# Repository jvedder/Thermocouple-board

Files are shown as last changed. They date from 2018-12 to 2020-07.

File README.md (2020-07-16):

# 4-channel Thermocouple PCB (MAX31855)
## Eagle CAD Schematic and PCB Layout
### Part Number: PCB100 Rev A

This design has 4 channels of **MAX31855** thermocouple amplifiers managed by
an **STM32F042K4** (or **'K6**) ARM Cortex-M0 processor.  Primary communication
and power is RS-485 over Cat 5 UTP Ethernet cables with a POE-like power scheme.
Both full and half-duplex communication schemes are supported. 

Secondary communication is over an **FTDI 232-TTL USB-to-UART** cable.  Direct
communication over **USB** to the STM32 is also supported by the layout (but
has not been tested). Each allow an instance of this board (perhaps without the
MAX31855 populated) to be the RS-485 controller and provide POE power to the
bus from either the USB connection or a 2x5.5 mm power connector.

The RJ-45 Pinout is compatible with the 8-pin modular connector pinout in
**ANSI E1.11-2008 (R2018)** 
 _DMX512-A Asynchronous Serial Digital Data Transmission Standard_  
but has not been tested for interoperability. 

Please note the RS-485 signal naming in this design matches the IC 
manufacturers' convention (A is non-inverting, B is inverting) which is
opposite the RS-485/RS-422 standard (A is inverting, B is non-inverting).

The RJ-45 pins selected for power are also compatible with 10/100 Base-T
Power over Ethernet (POE) in case of a cabling error. External power in the
range of 5V to 12V is supported, but there is little thermal margin on the
LDO at 12V. Lower than 5V is possible if the voltage drop over the cable
is managed.

### Part Number: PCB101 Rev A 

This revision:

- Adds a TPS25921 eFuse to the 2x5.5 mm connector that sources the POE power
injection to ensure that it is current limited.
- Inverts the polarity of the user button so that it can be used for the SMT32
boot loader function.
- Moves the FTDI USART port to PA9/PA10 to support the SMT32 boot loader
function.
- Moves the I2C port to pins PB6/PB7 (USART and I2C were swapped).
- Adds 3 pairs of holes for each channel so that the thermocouple leads can be
tied to the PCB for strain relief.
- Lengthens the PCB.
- Corrects pinout error on button orientation.

## License: ##

[MIT License](../master/LICENSE.txt)

----------------------

A portion of this design was leveraged from the 
**Adafruit Thermocouple Amplifier MAX31855 breakout board**. 
The Adafruit license is copied below. I support Adafruit's open-source hardware.

> Adafruit MAX31885 Thermocouple Amp breakout
> 
> These are the Eagle CAD files for the Adafruit MAX31885 Thermocouple Amp
> breakout:
> 
>   ----> http://www.adafruit.com/products/269
> 
> Adafruit invests time and resources providing this open source design,
> please support Adafruit and open-source hardware by purchasing products
> from Adafruit!
> 
> Thermocouples are very sensitive, requiring a good amplifier with a
> cold-compensation reference. The MAX31855K does everything for you, and can
> be easily interfaced with any microcontroller, even one without an analog
> input. This breakout board has the chip itself, a 3.3V regulator with 10uF
> bypass capacitors and level shifting circuitry, all assembled and tested.
> Comes with a 2 pin terminal block (for connecting to the thermocouple) and pin header (to plug into any breadboard or > perfboard). Goes great with our 1m K-type thermocouple. 
> 
> 
> All text above must be included in any redistribution
> 
> Designed by Limor Fried/Ladyada for Adafruit Industries.
> Creative Commons Attribution/Share-Alike, all text above must be included in
> any redistribution
>

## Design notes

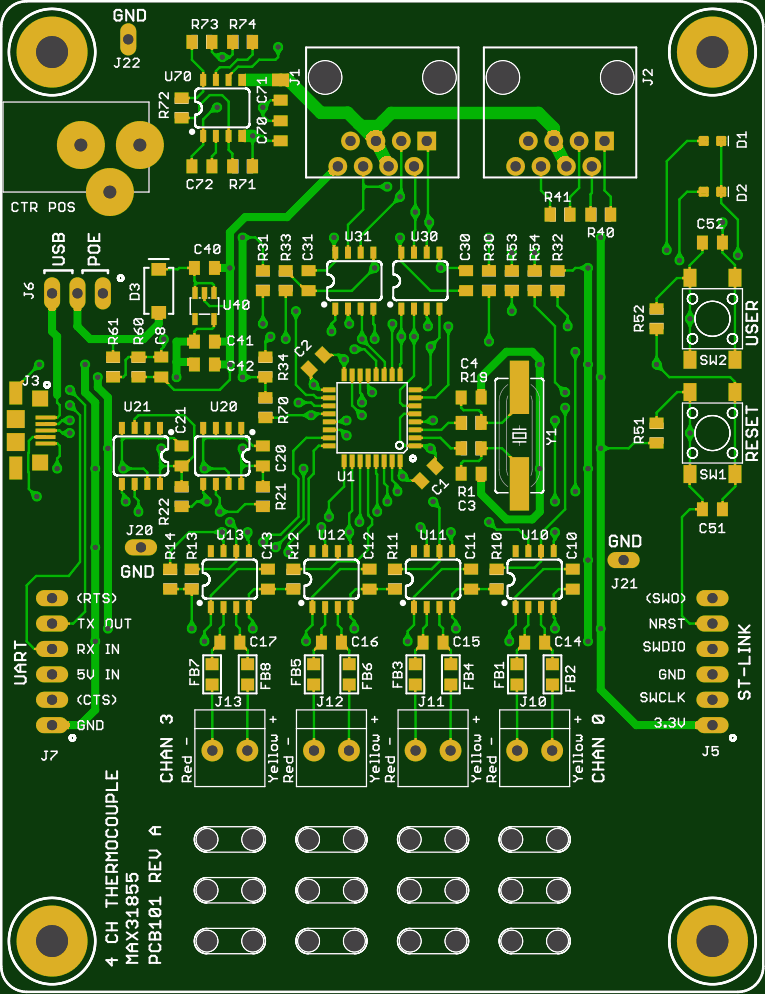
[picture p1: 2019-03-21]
PDF/PCB101_A/Seeed_PCB101_A_top.png

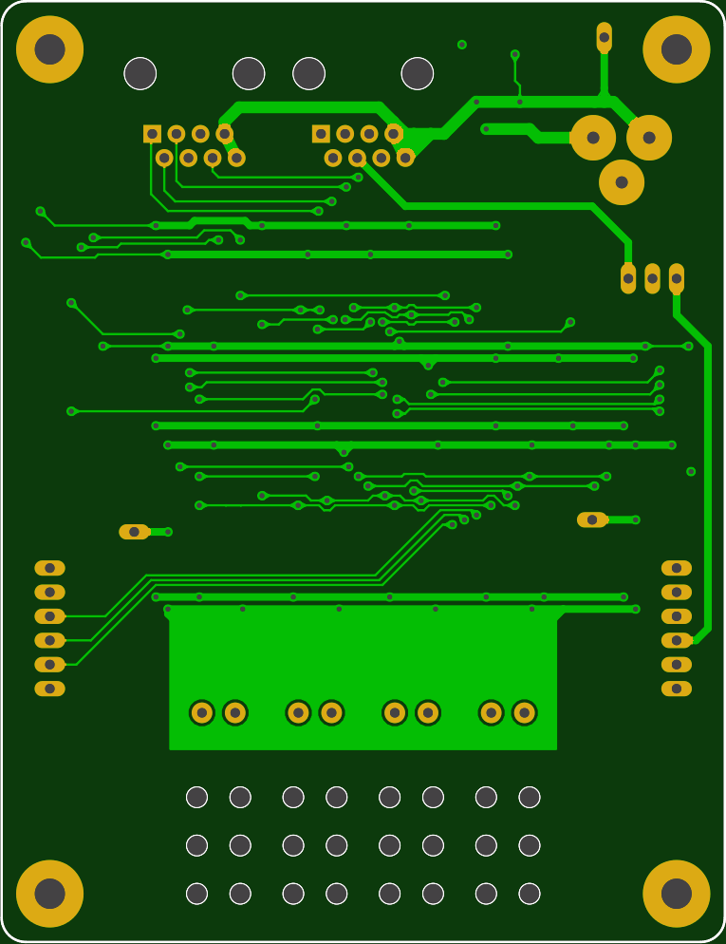
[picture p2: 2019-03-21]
PDF/PCB101_A/Seeed_PCB101_A_bottom.png

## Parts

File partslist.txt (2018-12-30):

Partlist

Exported from Thermocouple-board.brd at 12/27/18 10:27 PM

EAGLE Version 9.2.2 Copyright (c) 1988-2018 Autodesk, Inc.

Assembly variant: 

Part     Value          Package            Library                 Position (inch)       Orientation

C1       0.1uF          C0805K             adafruit                (1.78 1.24)           R225
C2       0.1uF          C0805K             adafruit                (1.34 1.68)           R45
C3       10pF           C0805K             adafruit                (1.95 1.24)           R0
C4       10pF           C0805K             adafruit                (1.95 1.54)           R0
C8       0.1uF          C0805K             adafruit                (0.72 1.66)           R270
C10      0.1uF          C0805K             adafruit                (2.32 0.82)           R90
C11      0.1uF          C0805K             adafruit                (1.93 0.82)           R90
C12      0.1uF          C0805K             adafruit                (1.54 0.82)           R90
C13      0.1uF          C0805K             adafruit                (1.15 0.82)           R90
C14      0.01uF         C0805K             adafruit                (2.17 0.57)           R0
C15      0.01uF         C0805K             adafruit                (1.78 0.57)           R0
C16      0.01uF         C0805K             adafruit                (1.39 0.57)           R0
C17      0.01uF         C0805K             adafruit                (1 0.57)              R0
C20      0.1uF          C0805K             adafruit                (0.59 1.28)           R270
C21      0.1uF          C0805K             adafruit                (0.91 1.28)           R270
C30      0.1uF          C0805K             adafruit                (1.93 2)              R90
C31      0.1uF          C0805K             adafruit                (1.31 2)              R270
C40      1uF            C0805K             adafruit                (0.9 2.05)            R0
C41      10uF           C0805K             adafruit                (0.9 1.76)            R0
C42      10uF           C0805K             adafruit                (0.9 1.67)            R0
C51      0.1uF          C0805K             adafruit                (2.6 1.51)            R180
C52      0.1uF          C0805K             adafruit                (2.59 1.94)           R180
D1       GREEN          LED-0603           SparkFun-LED            (2.24 2)              R90
D2       RED            LED-0603           SparkFun-LED            (2.33 2)              R90
D3       3A/40V/500mV   SMA-DIODE          SparkFun-DiscreteSemi   (0.72 1.96)           R90
FB1      Ferrite        _0805              microbuilder            (2.1 0.42)            R90
FB2      Ferrite        _0805              microbuilder            (2.24 0.42)           R90
FB3      Ferrite        _0805              microbuilder            (1.71 0.42)           R90
FB4      Ferrite        _0805              microbuilder            (1.85 0.42)           R90
FB5      Ferrite        _0805              microbuilder            (1.32 0.42)           R90
FB6      Ferrite        _0805              microbuilder            (1.46 0.42)           R90
FB7      Ferrite        _0805              microbuilder            (0.93 0.42)           R90
FB8      Ferrite        _0805              microbuilder            (1.07 0.42)           R90
J1       RJ45           RJ45-8             SparkFun-Connectors     (0.3 2.44)            R270
J2       RJ45           RJ45-8             SparkFun-Connectors     (2.7 2.44)            R90
J3       1981584-1      1981584-1          audio amplifier example (0 1.41)              R270
J4       2.1MMJACKTHM   PJ-102A            adafruit                (1.12 2.93)           R0
J5       ST-LINK        1X06_OVAL          Thermocouple-board      (2.8 0.75)            R90
J6       HEADER-1X3     1X03_OVAL          Thermocouple-board      (0.22 1.89)           R180
J7       UART           1X06_OVAL          Thermocouple-board      (0.2 0.75)            R270
J10      1X2-3.5MM      1X2-3.5MM          Thermocouple-board      (2.17 0.145)          R180
J11      1X2-3.5MM      1X2-3.5MM          Thermocouple-board      (1.78 0.145)          R180
J12      1X2-3.5MM      1X2-3.5MM          Thermocouple-board      (1.39 0.145)          R180
J13      1X2-3.5MM      1X2-3.5MM          Thermocouple-board      (1 0.145)             R180
MH1      4-40           MTG_HOLE_C280_H125 Thermocouple-board      (0.18 0.18)           R0
MH2      4-40           MTG_HOLE_C280_H125 Thermocouple-board      (2.82 0.18)           R0
MH3      4-40           MTG_HOLE_C280_H125 Thermocouple-board      (0.18 2.92)           R0
MH4      4-40           MTG_HOLE_C280_H125 Thermocouple-board      (2.82 2.92)           R0
R1       10K            R0805              adafruit                (1.95 1.34)           R180
R10      10K            R0805              adafruit                (2.02 0.82)           R90
R11      10K            R0805              adafruit                (1.63 0.82)           R90
R12      10K            R0805              adafruit                (1.24 0.82)           R90
R13      10K            R0805              adafruit                (0.85 0.82)           R90
R14      10K            R0805              adafruit                (0.76 0.82)           R90
R19      10K            R0805              adafruit                (1.95 1.44)           R180
R21      10K            R0805              adafruit                (0.59 1.45)           R90
R22      10K            R0805              adafruit                (0.91 1.45)           R90
R30      10K            R0805              adafruit                (2.02 2)              R270
R31      10K            R0805              adafruit                (1.13 2)              R270
R32      10K            R0805              adafruit                (2.11 2)              R90
R33      10K            R0805              adafruit                (1.22 2)              R90
R34      10K            R0805              adafruit                (1.14 1.66)           R90
R51      10K            R0805              adafruit                (2.6 1.39)            R0
R52      10K            R0805              adafruit                (2.59 1.82)           R0
R53      470            R0805              adafruit                (2.24 1.83)           R90
R54      470            R0805              adafruit                (2.33 1.83)           R90
R60      10K            R0805              adafruit                (0.63 1.66)           R270
R61      10K            R0805              adafruit                (0.54 1.66)           R270
R70      10K            R0805              adafruit                (0.63 0.93)           R90
SW1      PUSHBUTTON     PUSHBUTTON_6X6MM   Thermocouple-board      (2.81 1.45)           R270
SW2      PUSHBUTTON     PUSHBUTTON_6X6MM   Thermocouple-board      (2.81 1.88)           R270
U1       STM32F042K4    TQFP32-0.8MM       Thermocouple-board      (1.56 1.46)           R180
U10      MAX31855       SO08               adafruit                (2.17 0.82)           R0
U11      MAX31855       SO08               adafruit                (1.78 0.82)           R0
U12      MAX31855       SO08               adafruit                (1.39 0.82)           R0
U13      MAX31855       SO08               adafruit                (1 0.82)              R0
U20      EEPROM-I2C     SO08               Thermocouple-board      (0.75 1.28)           R0
U21      EEPROM-I2C     SO08               Thermocouple-board      (1.07 1.28)           R0
U30      ST3485         SO08               SparkFun-IC-Comms       (1.75 2)              R0
U31      ST3485         SO08               SparkFun-IC-Comms       (1.49 2)              R0
U40      LP298XS        SOT23-5L           adafruit                (0.9 1.9)             R180
Y1       8MHz           HC49UP             SparkFun-Clocks         (2.14 1.39)           R90

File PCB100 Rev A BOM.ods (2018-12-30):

Bill of Materials
4 Channel Thermocouple Board (MAX31855)
PCB100 Rev A
28-Dec-2018
Manufacturer Part Number | Manufacturer | Digi-Key Part Number | Customer Reference | Reference Designator | Packaging | Quantity | Unit Price | Extended Price | Description
KTR10EZPF4700 | Rohm Semiconductor | RHM470AHCT-ND |  | R53, R54 | Cut Tape (CT) | 2 | $0.1800 | $0.36 | RES SMD 470 OHM 1% 1/8W 0805
885342207005 | Wurth Electronics Inc. | 732-12105-1-ND |  | C14,C15,C16,C17 | Cut Tape (CT) | 4 | $0.1000 | $0.40 | CAP CER 10000PF 200V X7R 0805
885012207098 | Wurth Electronics Inc. | 732-8080-1-ND |  | C1,C2,C8,C10,C11,C12,C13,C20,C21,C30,C31,C51,C52 | Cut Tape (CT) | 13 | $0.0740 | $0.96 | CAP CER 0.1UF 50V X7R 0805
RMCF0805FT10K0 | Stackpole Electronics Inc. | RMCF0805FT10K0CT-ND |  | R1,R10,R11,R12,R13,R14,R19,R21,R22,R30,R31,R32,R33,R34,R51,R52,R60,R70 | Cut Tape (CT) | 18 | $0.0270 | $0.49 | RES 10K OHM 1% 1/8W 0805
885012007051 | Wurth Electronics Inc. | 732-7846-1-ND |  | C3,C4 | Cut Tape (CT) | 2 | $0.1000 | $0.20 | CAP CER 10PF 50V C0G/NP0 0805
CL21A106KOQNNNE | Samsung Electro-Mechanics | 1276-1096-1-ND |  | C41,C42 | Cut Tape (CT) | 2 | $0.2100 | $0.42 | CAP CER 10UF 16V X5R 0805
10104111-0001LF | Amphenol ICC (FCI) | 609-4053-1-ND |  | J3 | Cut Tape (CT) | 1 | $0.8100 | $0.81 | CONN RCPT USB2.0 MICRO AB SMD RA
CL21B105KAFNNNE | Samsung Electro-Mechanics | 1276-1066-1-ND |  | C40 | Cut Tape (CT) | 1 | $0.1100 | $0.11 | CAP CER 1UF 25V X7R 0805
YO0201500000G | Amphenol Anytek | 609-4725-ND |  | J10,J11,J12,J13 | Bulk | 4 | $0.7300 | $2.92 | TERM BLK 2POS SIDE ENT 3.5MM PCB
PJ-102A | CUI Inc. | CP-102A-ND |  | J4 | Tray | 1 | $0.6700 | $0.67 | CONN PWR JACK 2X5.5MM SOLDER
B340AE-13 | Diodes Incorporated | B340AE-13DICT-ND |  | D3 | Cut Tape (CT) | 1 | $0.4000 | $0.40 | DIODE SCHOTTKY 40V 2A SMA
ABLS-8.000MHZ-B4-T | Abracon LLC | 535-10212-1-ND |  | Y1 | Cut Tape (CT) | 1 | $0.2700 | $0.27 | CRYSTAL 8.0000MHZ 18PF SMD
BKP2125HS600-T | Taiyo Yuden | 587-1932-1-ND | Alternate 1 | FB1,FB2,FB3,FB4,FB5,FB6,FB7,FB8 | Cut Tape (CT) | 8 | $0.1000 | $0.80 | FERRITE BEAD 60 OHM 0805 1LN
BK2125HM601-T | Taiyo Yuden | 587-1902-1-ND | Alternate 2 | FB1,FB2,FB3,FB4,FB5,FB6,FB7,FB8 | Cut Tape (CT) | 8 | $0.1000 | $0.80 | FERRITE BEAD 600 OHM 0805 1LN
LTST-C190KGKT | Lite-On Inc. | 160-1435-1-ND |  | D1 | Cut Tape (CT) | 1 | $0.2700 | $0.27 | LED GREEN CLEAR CHIP SMD
LTST-C190KRKT | Lite-On Inc. | 160-1436-1-ND |  | D2 | Cut Tape (CT) | 1 | $0.2700 | $0.27 | LED RED CLEAR CHIP SMD
LP2985-33DBVR | Texas Instruments | 296-18476-1-ND |  | U40 | Cut Tape (CT) | 1 | $0.6000 | $0.60 | IC REG LINEAR 3.3V 150MA SOT23-5
MAX31855KASA+ | Maxim Integrated | MAX31855KASA+-ND |  | U10,U11,U12,U13 | Tube | 4 | $4.5000 | $18.00 | IC CONV THERMOCOUPLE-DGTL SOIC
PTS645SL50SMTR92 LFS | C&K | CKN9088CT-ND | BLACK | SW1 | Cut Tape (CT) | 1 | $0.1700 | $0.17 | SWITCH TACTILE SPST-NO 0.05A 12V
PTS645SM50SMTR92 LFS | C&K | CKN10889CT-ND | BLUE | SW2 | Cut Tape (CT) | 1 | $0.2700 | $0.27 | SWITCH TACTILE SPST-NO 0.05A 12V
54602-908LF | Amphenol ICC (FCI) | 609-1046-ND |  | J1,J2 | Bulk | 2 | $0.6000 | $1.20 | CONN MOD JACK 8P8C R/A UNSHLD
ST3485ECDR | STMicroelectronics | 497-6540-1-ND |  | U30,U31 | Cut Tape (CT) | 2 | $1.5900 | $3.18 | IC TXRX RS422/485 15MBPS 8SO
STM32F042K6T6 | STMicroelectronics | 497-14647-ND |  | U1 | Tray | 1 | $3.0100 | $3.01 | IC MCU 32BIT 32KB FLASH 32LQFP
CR0805-FX-3012ELF | Bourns Inc. | CR0805-FX-3012ELFCT-ND |  | C61 | Cut Tape (CT) | 1 | $0.1000 | $0.10 | RES SMD 30.1K OHM 1% 1/8W 0805
CRG0805F750R | TE Connectivity Passive Product | A126385CT-ND |  | TERM-BIAS2 | Cut Tape (CT) | 2 | $0.1000 | $0.20 | RES SMD 750 OHM 1% 1/8W 0805
RC0805FR-07137RL | Yageo | 311-137CRCT-ND |  | TERM-BIAS1 | Cut Tape (CT) | 1 | $0.1000 | $0.10 | RES SMD 137 OHM 1% 1/8W 0805
RC0805FR-07100RL | Yageo | 311-100CRCT-ND |  | TERM | Cut Tape (CT) | 1 | $0.1000 | $0.10 | RES SMD 100 OHM 1% 1/8W 0805
Header, 1x3 |  |  | On-Hand | J6 |  | 1 |  |  | Header, 1x3, 0.1-inch
Header, 1x6 |  |  | On-Hand | J5, J7 |  | 2 |  |  | Header, 1x6, 0.1-inch
 |  |  |  |  | Totals | 85 |  | $37.08

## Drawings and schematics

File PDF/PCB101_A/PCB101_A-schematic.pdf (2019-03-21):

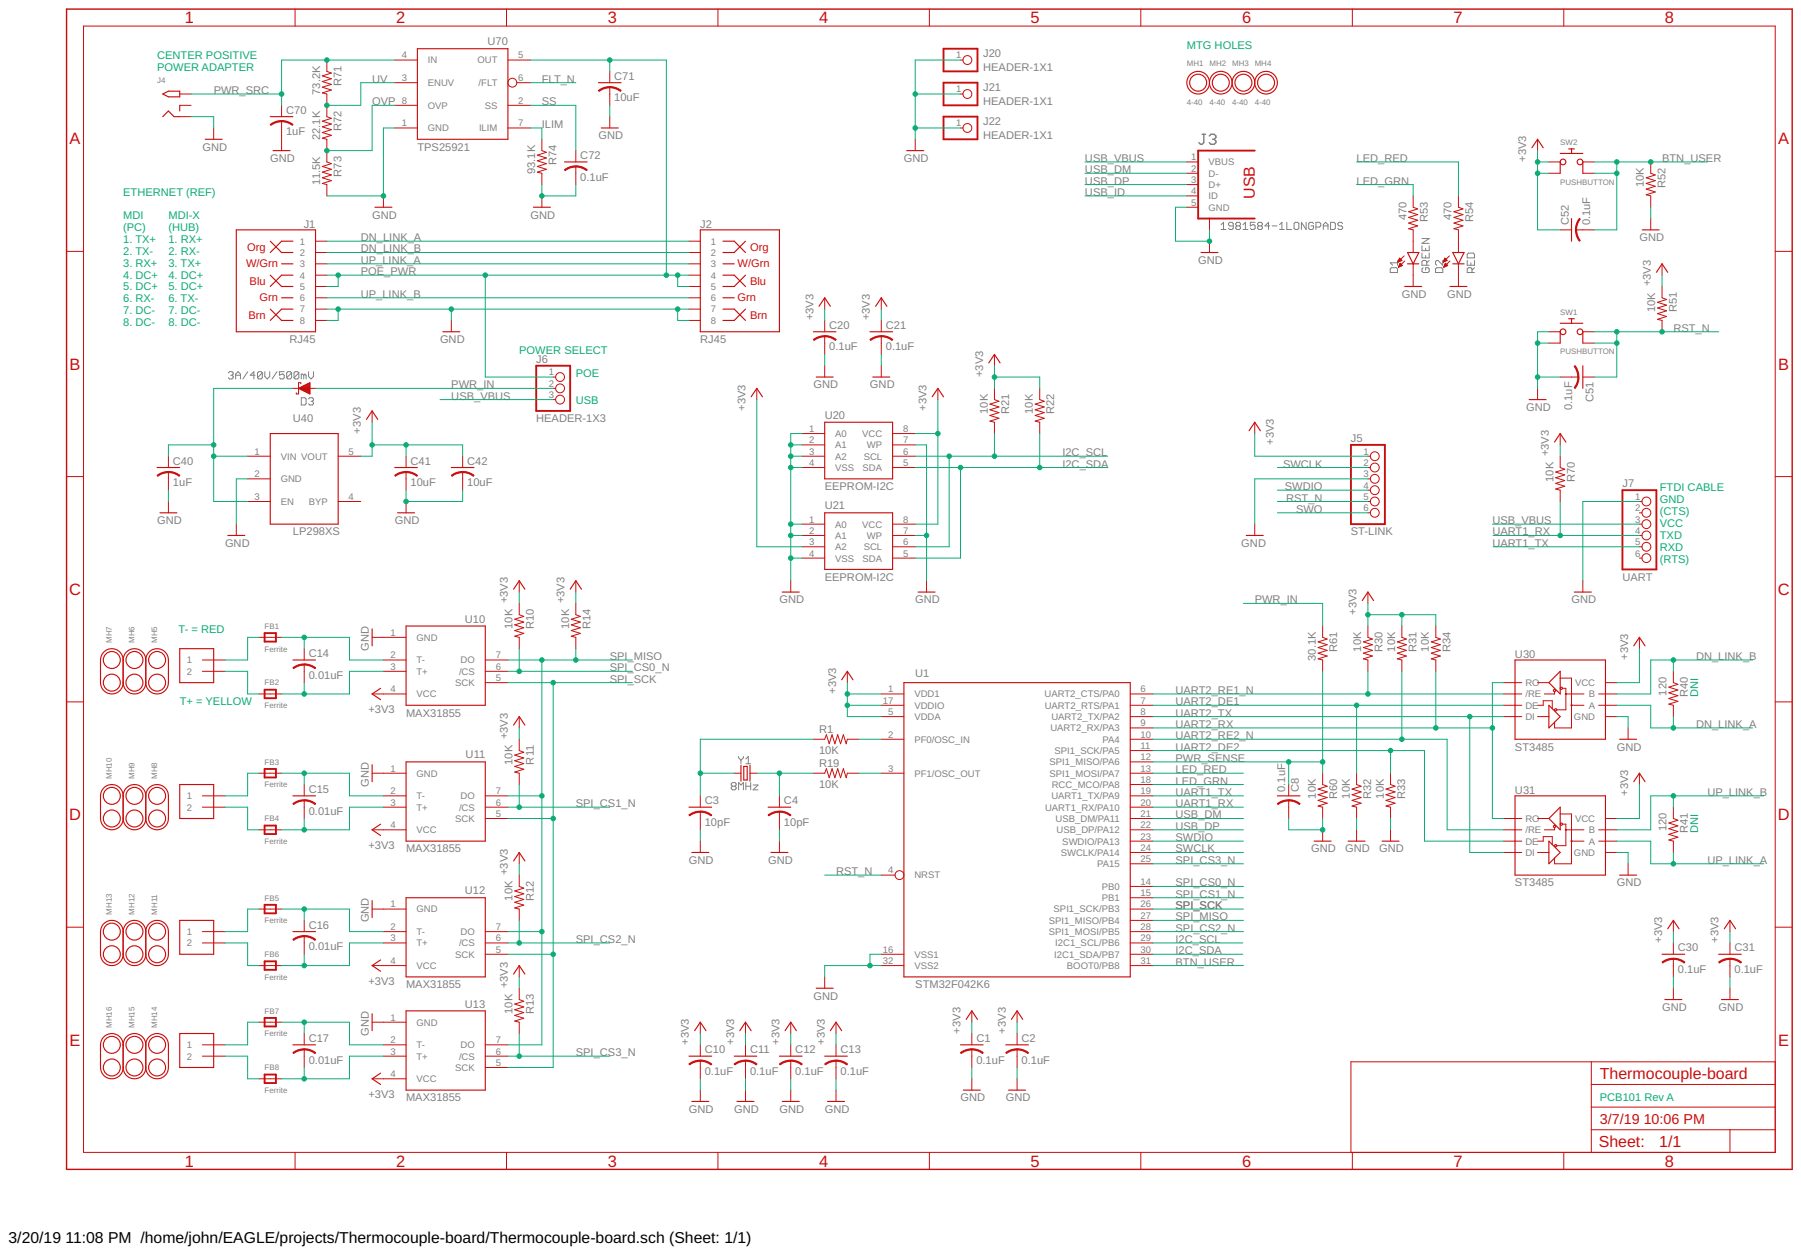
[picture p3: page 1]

MTG HOLES

POE_PWR | Blu Brn W/Grn Grn Org

UP_LINK_B

3/20/19 11:08 PM /home/john/EAGLE/projects/Thermocouple-board/Thermocouple-board.sch (Sheet: 1/1)

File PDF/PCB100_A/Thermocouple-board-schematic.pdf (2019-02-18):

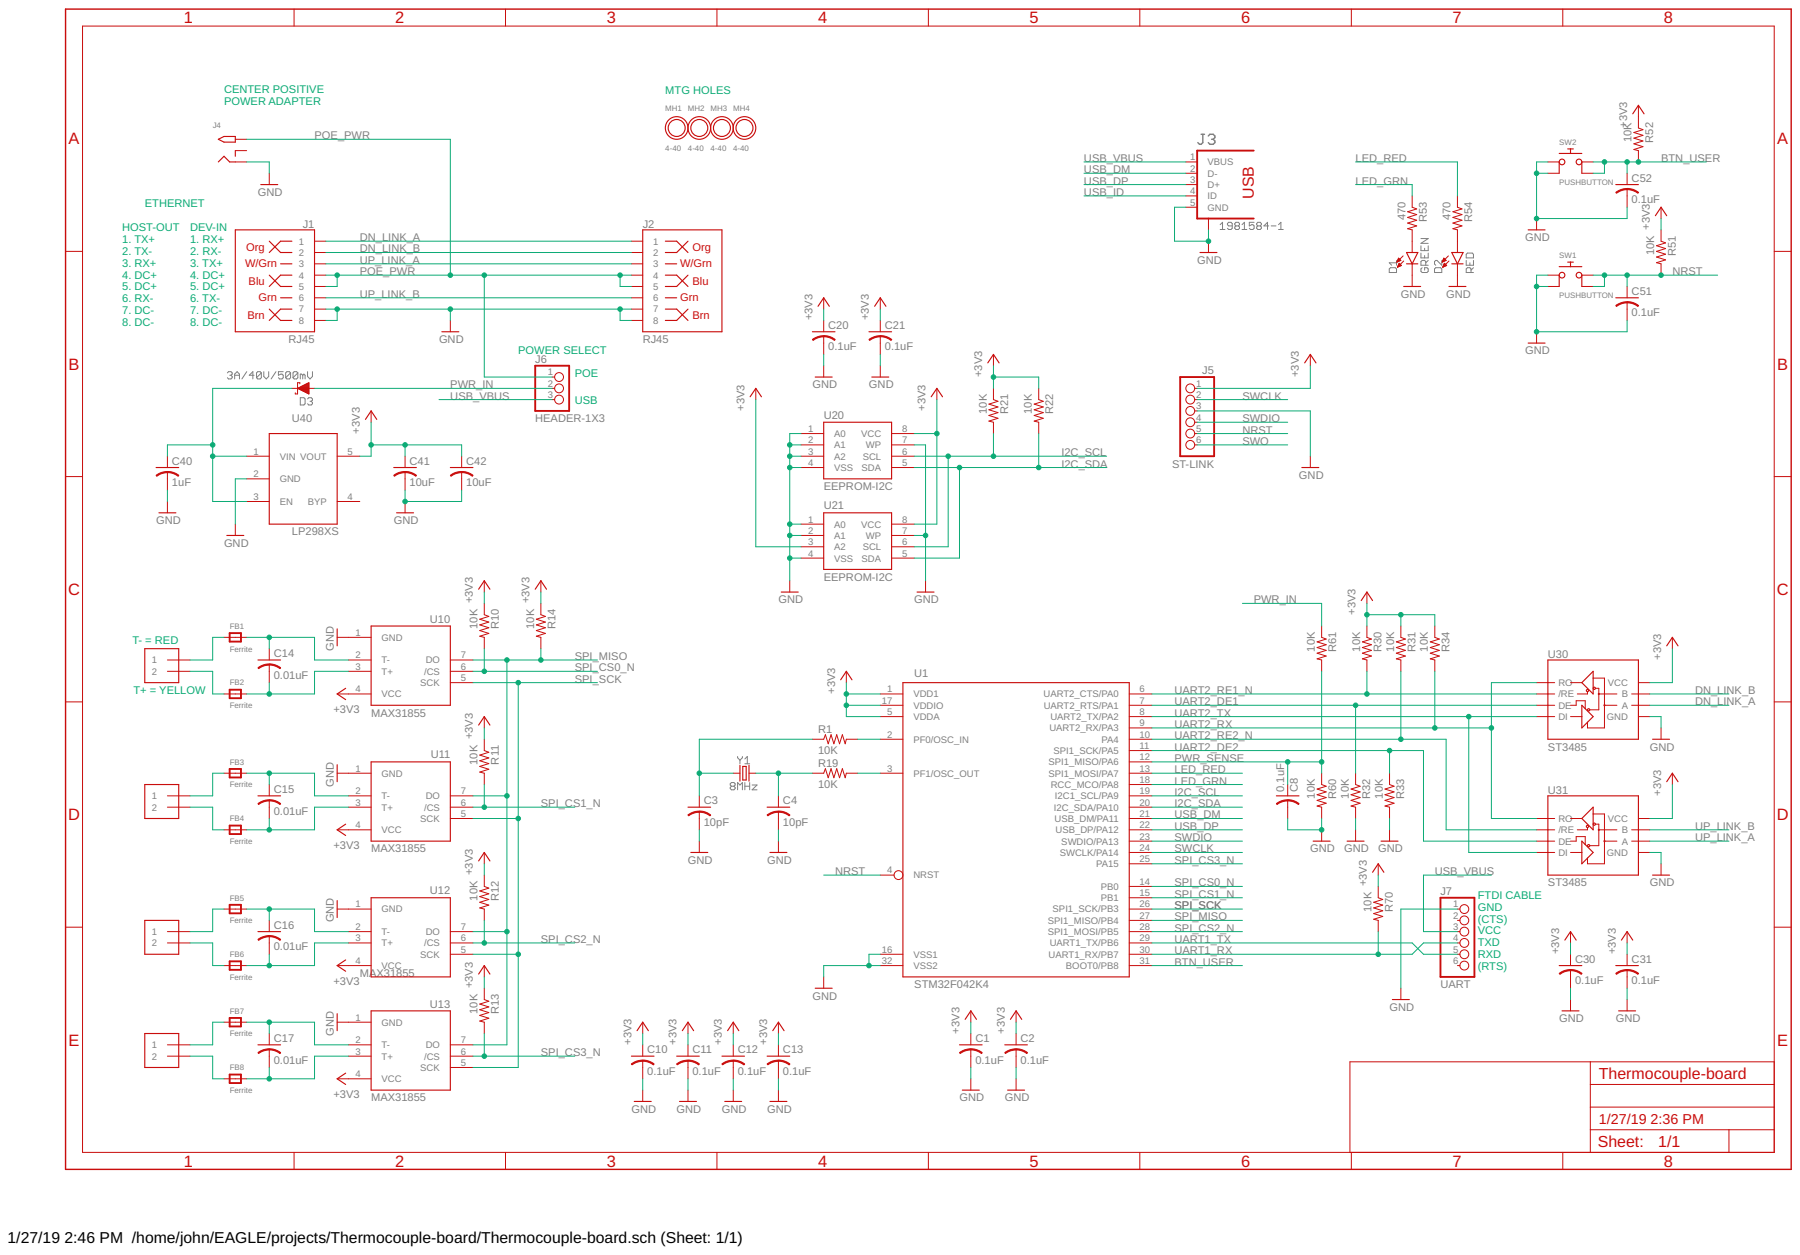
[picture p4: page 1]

POE_PWR | Blu Brn W/Grn Grn Org

UP_LINK_B

1/27/19 2:46 PM /home/john/EAGLE/projects/Thermocouple-board/Thermocouple-board.sch (Sheet: 1/1)

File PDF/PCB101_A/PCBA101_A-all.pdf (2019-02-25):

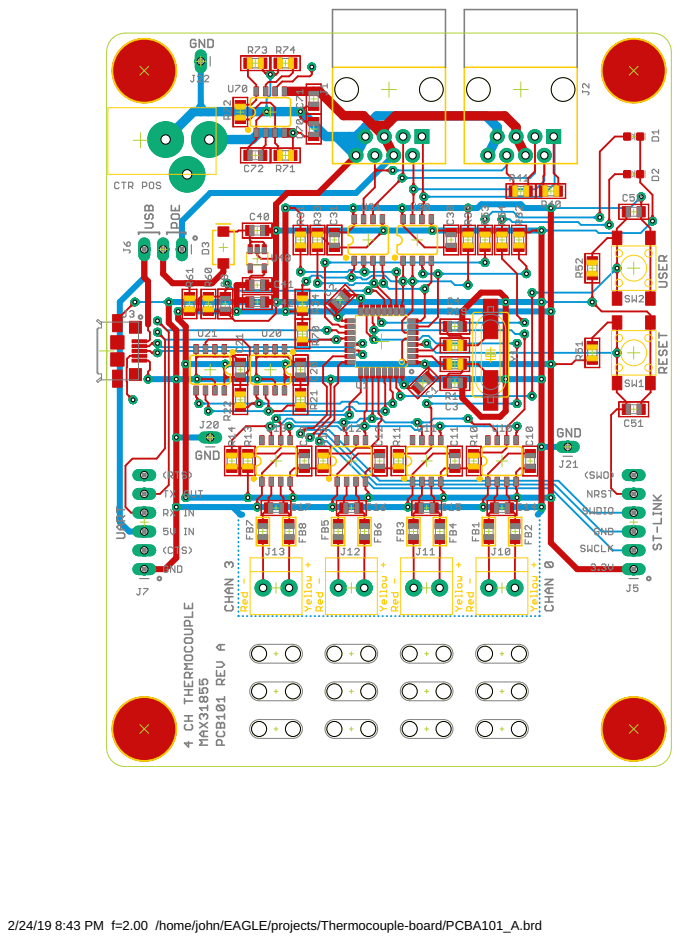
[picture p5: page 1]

2/24/19 8:43 PM f=2.00 /home/john/EAGLE/projects/Thermocouple-board/PCBA101_A.brd

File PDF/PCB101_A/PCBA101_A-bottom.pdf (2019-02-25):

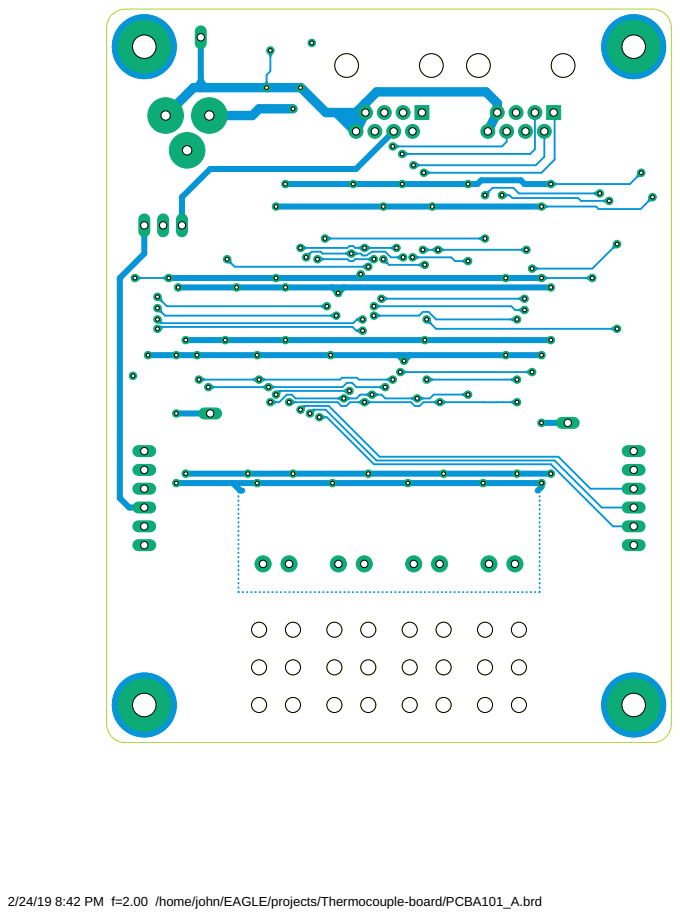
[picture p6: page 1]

2/24/19 8:42 PM f=2.00 /home/john/EAGLE/projects/Thermocouple-board/PCBA101_A.brd

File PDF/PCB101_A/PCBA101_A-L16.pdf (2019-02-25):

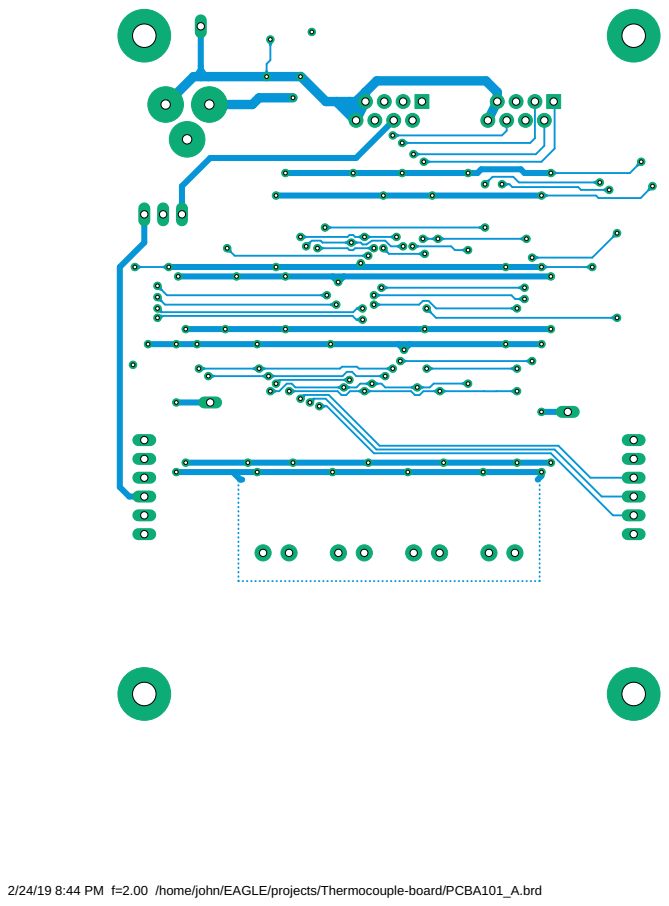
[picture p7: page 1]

2/24/19 8:44 PM f=2.00 /home/john/EAGLE/projects/Thermocouple-board/PCBA101_A.brd

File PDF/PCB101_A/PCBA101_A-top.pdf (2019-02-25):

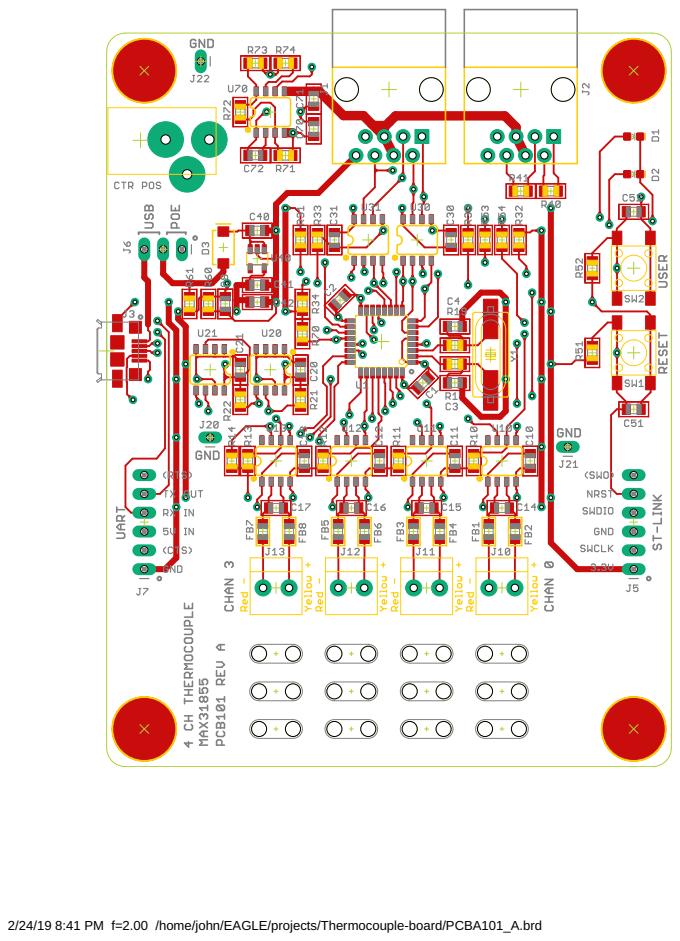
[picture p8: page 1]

2/24/19 8:41 PM f=2.00 /home/john/EAGLE/projects/Thermocouple-board/PCBA101_A.brd

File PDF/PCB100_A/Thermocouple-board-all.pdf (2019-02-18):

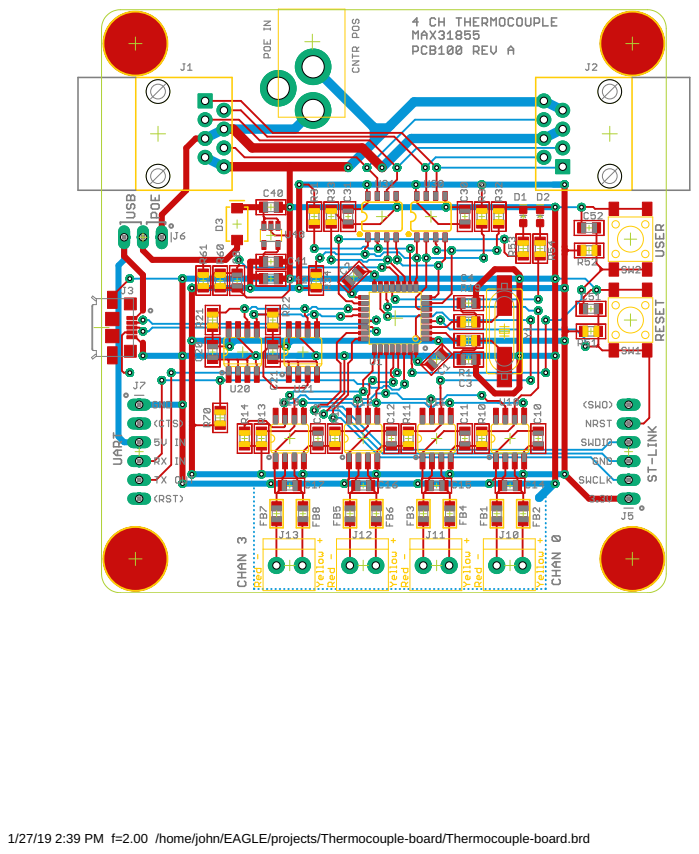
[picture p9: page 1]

1/27/19 2:39 PM f=2.00 /home/john/EAGLE/projects/Thermocouple-board/Thermocouple-board.brd

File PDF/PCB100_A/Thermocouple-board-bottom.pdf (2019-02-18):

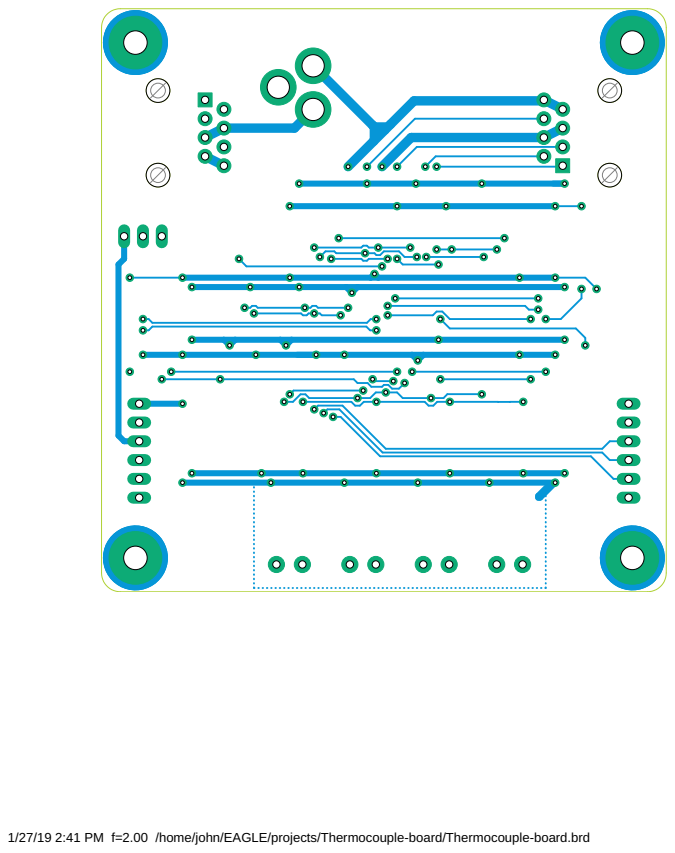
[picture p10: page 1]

1/27/19 2:41 PM f=2.00 /home/john/EAGLE/projects/Thermocouple-board/Thermocouple-board.brd

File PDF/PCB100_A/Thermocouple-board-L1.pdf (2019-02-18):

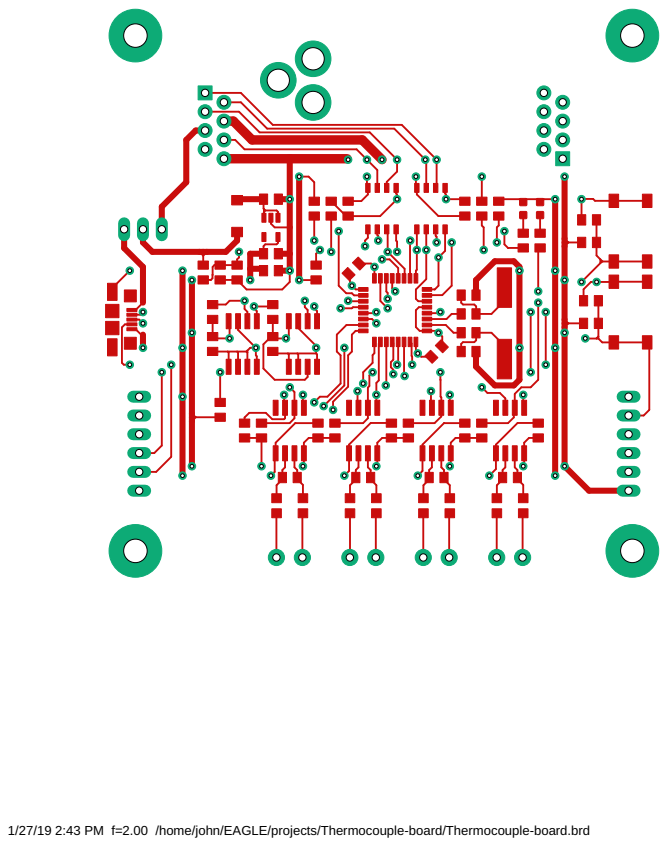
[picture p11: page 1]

1/27/19 2:43 PM f=2.00 /home/john/EAGLE/projects/Thermocouple-board/Thermocouple-board.brd

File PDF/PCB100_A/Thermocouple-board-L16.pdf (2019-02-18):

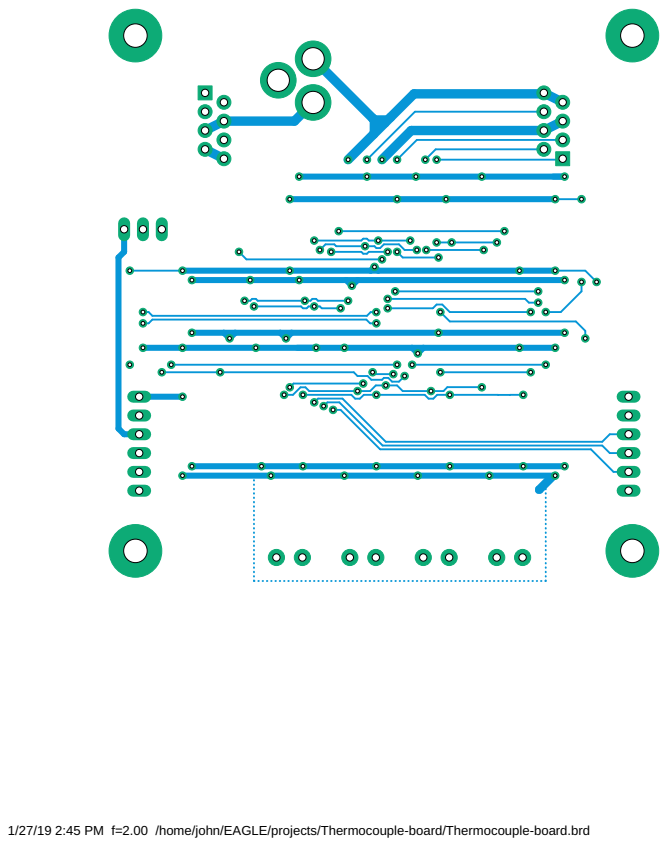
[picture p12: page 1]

1/27/19 2:45 PM f=2.00 /home/john/EAGLE/projects/Thermocouple-board/Thermocouple-board.brd

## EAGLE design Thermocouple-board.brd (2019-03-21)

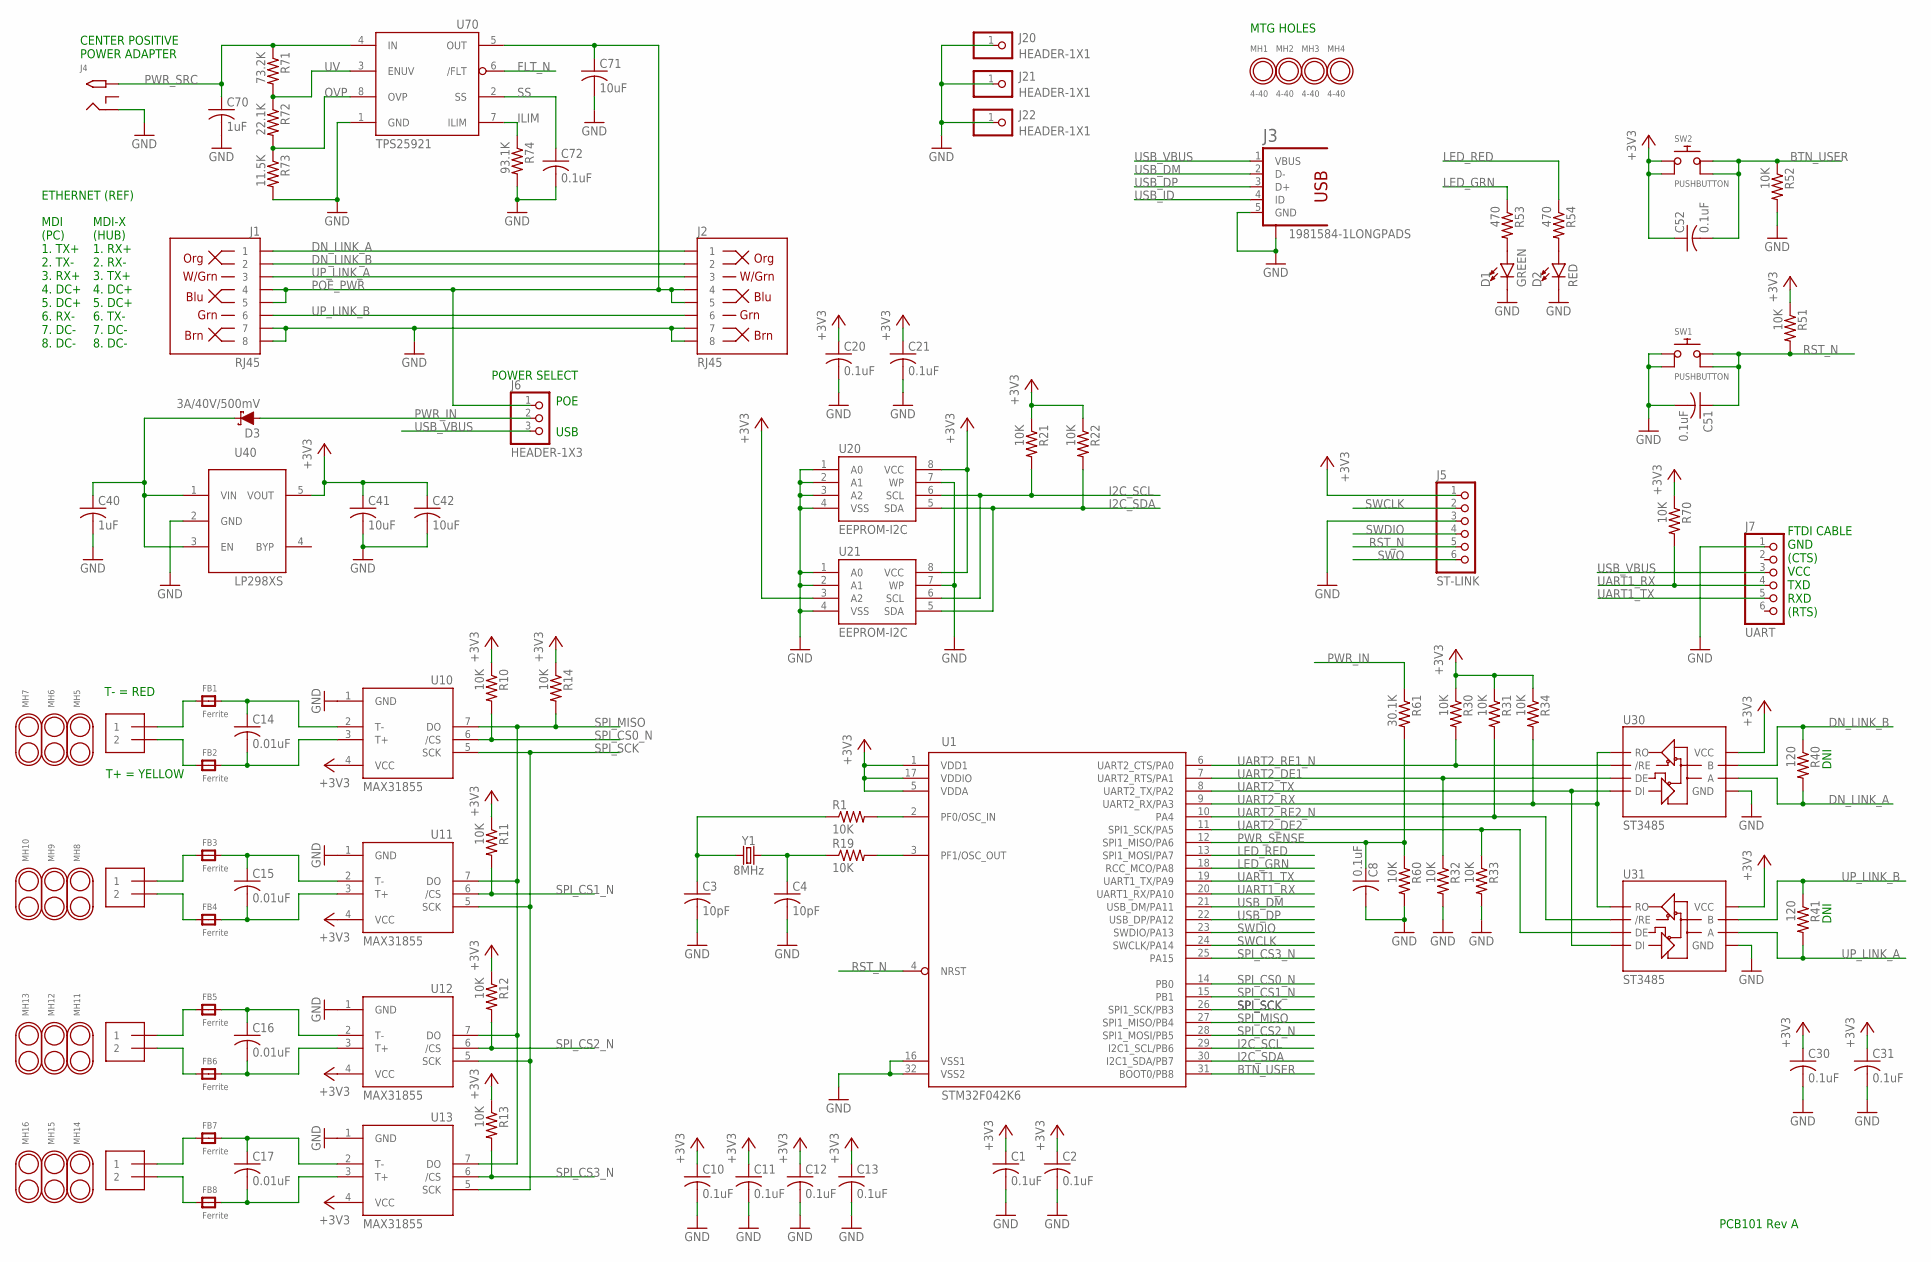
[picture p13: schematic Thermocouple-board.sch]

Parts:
C1, C2, C8, C10, C11, C12, C13, C20, C21, C30, C31, C51, C52, C72: 0.1uF; C0805K
C3, C4: 10pF; C0805K
C14, C15, C16, C17: 0.01uF; C0805K
C40, C70: 1uF; C0805K
C41, C42, C71: 10uF; C0805K
D1: GREEN; LED-0603
D2: RED; LED-0603
D3: 3A/40V/500mV; SMA-DIODE
FB1, FB2, FB3, FB4, FB5, FB6, FB7, FB8: Ferrite; _0805
J1, J2: RJ45; RJ45-8
J3: 1981584-1LONGPADS; 1981584-1-LONG
J4: 2.1MMJACKTHM; PJ-102A
J5: ST-LINK; 1X06_OVAL
J6: HEADER-1X3; 1X03_OVAL
J7: UART; 1X06_OVAL
J10, J11, J12, J13: 1X2-3.5MM
J20, J21, J22: HEADER-1X1; 1X01_OVAL
MH1, MH2, MH3, MH4: 4-40; MTG_HOLE_C280_H125
MH5, MH6, MH7, MH8, MH9, MH10, MH11, MH12, MH13, MH14, MH15, MH16: HOLD_DOWN
R1, R10, R11, R12, R13, R14, R19, R21, R22, R30, R31, R32, R33, R34, R51, R52, R60, R70: 10K; R0805
R40, R41: 120; R0805
R53, R54: 470; R0805
R61: 30.1K; R0805
R71: 73.2K; R0805
R72: 22.1K; R0805
R73: 11.5K; R0805
R74: 93.1K; R0805
SW1, SW2: PUSHBUTTON; PUSHBUTTON_6X6MM
U1: STM32F042K6; TQFP32-0.8MM
U10, U11, U12, U13: MAX31855; SO08
U20, U21: EEPROM-I2C; SO08
U30, U31: ST3485; SO08
U40: LP298XS; SOT23-5L
U70: TPS25921; SO08
Y1: 8MHz; HC49UP

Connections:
+3V3: C1.1, C2.1, C10.1, C11.1, C12.1, C13.1, C20.1, C21.1, C30.1, C31.1, C41.1, C42.1, C52.1, J5.1, R10.1, R11.1, R12.1, R13.1, R14.1, R21.1, R22.1, R30.1, R31.1, R34.1, R51.1, R70.1, SW2.1, SW2.2, U1.1 (VDD1), U1.5 (VDDA), U1.17 (VDDIO), U10.4 (VCC), U11.4 (VCC), U12.4 (VCC), U13.4 (VCC), U20.8 (VCC), U21.3 (A2), U21.8 (VCC), U30.8 (VCC), U31.8 (VCC), U40.5 (VOUT)
BTN_USER: C52.2, R52.1, SW2.3, SW2.4, U1.31 (BOOT0/PB8)
DN_LINK_A: J1.1, J2.1, R40.2, U30.6 (A)
DN_LINK_B: J1.2, J2.2, R40.1, U30.7 (B)
FLT_N: U70.6 (/FLT)
GND: C1.2, C2.2, C3.2, C4.2, C8.2, C10.2, C11.2, C12.2, C13.2, C20.2, C21.2, C30.2, C31.2, C40.2, C41.2, C42.2, C51.2, C70.2, C71.2, C72.2, D1.C, D2.C, J1.7, J1.8, J2.7, J2.8, J3.5 (GND), J3.S1, J4.RING, J5.3, J7.1, J20.1, J21.1, J22.1, R32.2, R33.2, R52.2, R60.2, R73.2, R74.2, SW1.1, SW1.2, U1.16 (VSS1), U1.32 (VSS2), U10.1 (GND), U11.1 (GND), U12.1 (GND), U13.1 (GND), U20.1 (A0), U20.2 (A1), U20.3 (A2), U20.4 (VSS), U20.7 (WP), U21.1 (A0), U21.2 (A1), U21.4 (VSS), U21.7 (WP), U30.5 (GND), U31.5 (GND), U40.2 (GND), U70.1 (GND)
I2C_SCL: R21.2, U1.29 (I2C1_SCL/PB6), U20.6 (SCL), U21.6 (SCL)
I2C_SDA: R22.2, U1.30 (I2C1_SDA/PB7), U20.5 (SDA), U21.5 (SDA)
ILIM: R74.1, U70.7 (ILIM)
LED_GRN: R53.1, U1.18 (RCC_MCO/PA8)
LED_RED: R54.1, U1.13 (SPI1_MOSI/PA7)
unnamed: FB1.1, J10.1
unnamed: R1.2, U1.2 (PF0/OSC_IN)
unnamed: R19.2, U1.3 (PF1/OSC_OUT)
unnamed: C14.1, FB1.2, U10.2 (T-)
unnamed: FB2.1, J10.2
unnamed: C14.2, FB2.2, U10.3 (T+)
unnamed: FB3.1, J11.1
unnamed: C15.1, FB3.2, U11.2 (T-)
unnamed: FB4.1, J11.2
unnamed: C15.2, FB4.2, U11.3 (T+)
unnamed: FB5.1, J12.1
unnamed: C16.1, FB5.2, U12.2 (T-)
unnamed: FB6.1, J12.2
unnamed: C16.2, FB6.2, U12.3 (T+)
unnamed: FB7.1, J13.1
unnamed: C17.1, FB7.2, U13.2 (T-)
unnamed: FB8.1, J13.2
unnamed: C17.2, FB8.2, U13.3 (T+)
unnamed: C4.1, R19.1, Y1.2
unnamed: C3.1, R1.1, Y1.1
unnamed: C40.1, D3.C, U40.1 (VIN), U40.3 (EN)
unnamed: D1.A, R53.2
unnamed: D2.A, R54.2
OVP: R72.2, R73.1, U70.8 (OVP)
POE_PWR: C71.1, J1.4, J1.5, J2.4, J2.5, J6.1, U70.5 (OUT)
PWR_IN: D3.A, J6.2, R61.1
PWR_SENSE: C8.1, R60.1, R61.2, U1.12 (SPI1_MISO/PA6)
PWR_SRC: C70.1, J4.TIP, R71.1, U70.4 (IN)
RST_N: C51.1, J5.5, R51.2, SW1.3, SW1.4, U1.4 (NRST)
SPI_CS0_N: R10.2, U1.14 (PB0), U10.6 (/CS)
SPI_CS1_N: R11.2, U1.15 (PB1), U11.6 (/CS)
SPI_CS2_N: R12.2, U1.28 (SPI1_MOSI/PB5), U12.6 (/CS)
SPI_CS3_N: R13.2, U1.25 (PA15), U13.6 (/CS)
SPI_MISO: R14.2, U1.27 (SPI1_MISO/PB4), U10.7 (DO), U11.7 (DO), U12.7 (DO), U13.7 (DO)
SPI_SCK: U1.26 (SPI1_SCK/PB3), U10.5 (SCK), U11.5 (SCK), U12.5 (SCK), U13.5 (SCK)
SS: C72.1, U70.2 (SS)
SWCLK: J5.2, U1.24 (SWCLK/PA14)
SWDIO: J5.4, U1.23 (SWDIO/PA13)
SWO: J5.6
UART1_RX: J7.4, R70.2, U1.20 (UART1_RX/PA10)
UART1_TX: J7.5, U1.19 (UART1_TX/PA9)
UART2_DE1: R32.1, U1.7 (UART2_RTS/PA1), U30.3 (DE)
UART2_DE2: R33.1, U1.11 (SPI1_SCK/PA5), U31.3 (DE)
UART2_RE1_N: R30.2, U1.6 (UART2_CTS/PA0), U30.2 (/RE)
UART2_RE2_N: R31.2, U1.10 (PA4), U31.2 (/RE)
UART2_RX: R34.2, U1.9 (UART2_RX/PA3), U30.1 (RO), U31.1 (RO)
UART2_TX: U1.8 (UART2_TX/PA2), U30.4 (DI), U31.4 (DI)
UP_LINK_A: J1.3, J2.3, R41.2, U31.6 (A)
UP_LINK_B: J1.6, J2.6, R41.1, U31.7 (B)
USB_DM: J3.2 (D-), U1.21 (USB_DM/PA11)
USB_DP: J3.3 (D+), U1.22 (USB_DP/PA12)
USB_ID: J3.4 (ID)
USB_VBUS: J3.1 (VBUS), J6.3, J7.3
UV: R71.2, R72.1, U70.3 (ENUV)

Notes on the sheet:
T+ = YELLOW
T- = RED
MDI-X (HUB) 1. RX+ 2. RX- 3. TX+ 4. DC+ 5. DC+ 6. TX- 7. DC- 8. DC-
MDI (PC) 1. TX+ 2. TX- 3. RX+ 4. DC+ 5. DC+ 6. RX- 7. DC- 8. DC-
ETHERNET (REF)
MTG HOLES
POWER SELECT
CENTER POSITIVE POWER ADAPTER
POE
USB
FTDI CABLE GND (CTS) VCC TXD RXD (RTS)
PCB101 Rev A
DNI

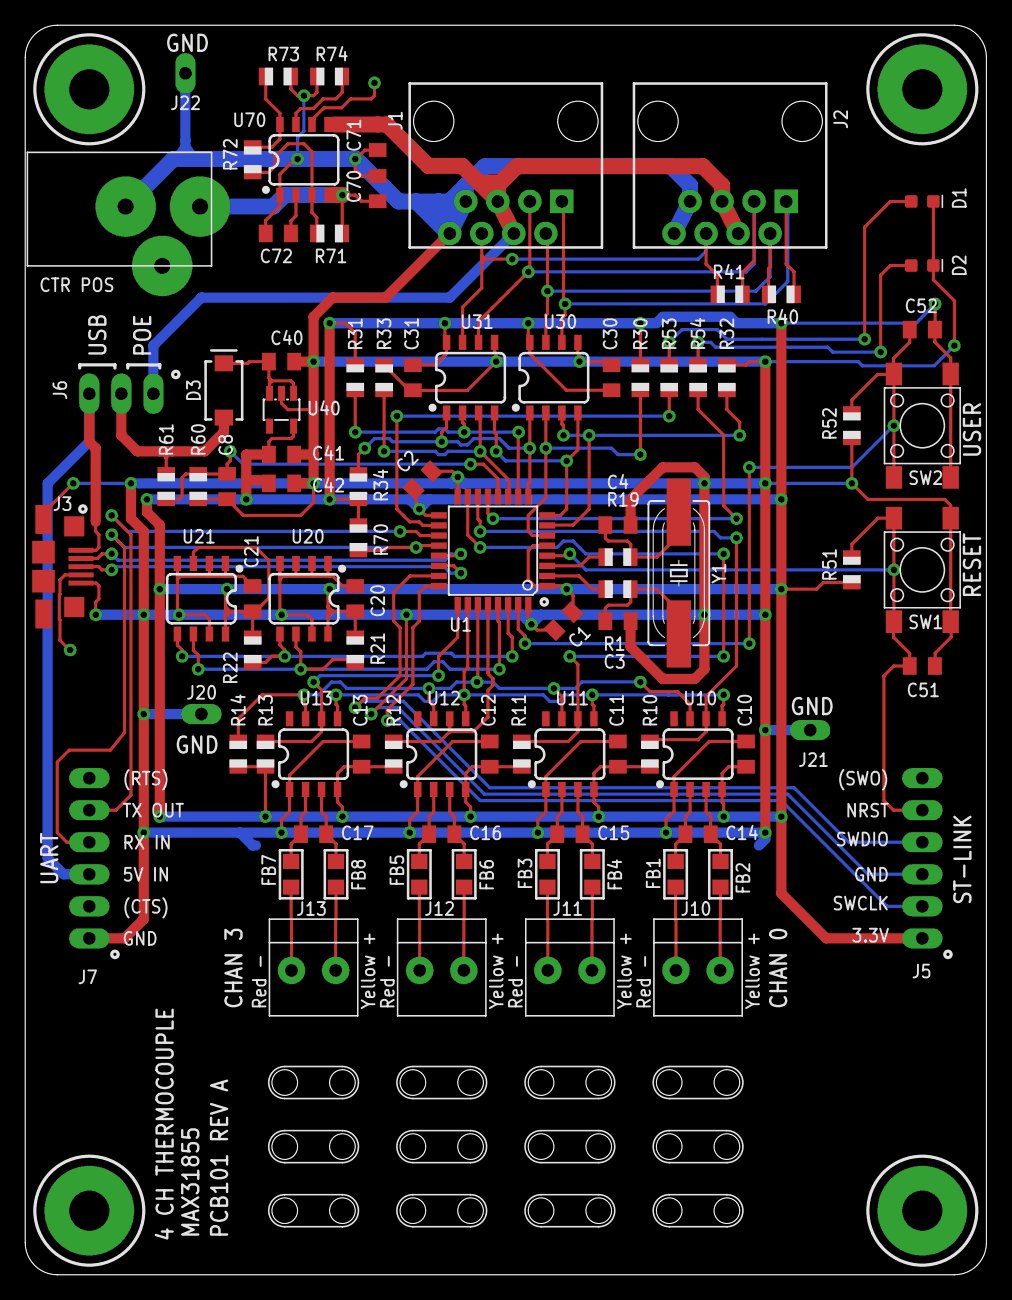
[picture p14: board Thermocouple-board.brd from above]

Board: 2 copper layers, 76.2 x 99.1 mm, 107 parts (0 on the bottom side), 62 nets.

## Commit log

2018-11-30 Last with 74LVC1G125
    [Thermocouple-board.brd, Thermocouple-board.sch]
2018-11-30 WIP Updating with RS-485 transceivers
    [Thermocouple-board.brd, Thermocouple-board.sch]
2018-12-05 WIP Routing
    [Thermocouple-board.brd, Thermocouple-board.sch]
2018-12-14 Start of move to STM32F042K4 with USB
    [Thermocouple-board.brd, Thermocouple-board.sch]
2018-12-15 Ripup and start rerouting with USB and Xtal
    [Thermocouple-board.brd, Thermocouple-board.sch]
2018-12-16 Before replacement of EEPROM
    [Thermocouple-board.brd, Thermocouple-board.sch]
2018-12-17 Wip routing. Updated DRC to Sparkfun and 20 mil vias with 10 mil annualar ring
    [Thermocouple-board.brd]
2018-12-18 First pass routing commplete
    [Thermocouple-board.brd]
2018-12-18 Upgraded diodes; start of adding 5.5/2.5mm power connector
    [Thermocouple-board.brd, Thermocouple-board.sch]
2018-12-22 Routing complete
    [Thermocouple-board.brd, Thermocouple-board.sch]
2018-12-22 Cleanup errors
    [Thermocouple-board.brd]
2018-12-22 More Cleanup
    [Thermocouple-board.brd, Thermocouple-board.sch]
2018-12-25 WIP on larger MTG holes
    [Thermocouple-board.brd, Thermocouple-board.sch, partslist.ods]
2018-12-26 Reconfigured UARTs for FTDI cable
    [Thermocouple-board.brd, Thermocouple-board.sch]
2018-12-26 Finish routing.
    [Thermocouple-board.brd, Thermocouple-board.sch]
2018-12-27 Finish cleanup. Added schem frame.
    [Thermocouple-board.brd, Thermocouple-board.sch]
2018-12-27 Added notes to UART connector
    [Thermocouple-board.sch]
2018-12-28 Added Teardrops and released Gerbers
    [Thermocouple-board.brd]
2018-12-30 Updated BOM and README.md
    [PCB100 Rev A BOM.ods, partslist.ods]
2019-01-11 revert .brd to pre-teardrops
    [Thermocouple-board.brd]
2019-02-18 Fix pushbutton and SO08. Start of efuse.
    [Thermocouple-board.brd, Thermocouple-board.sch]
2019-02-19 RJ-45 rework routing WIP
    [Thermocouple-board.brd, Thermocouple-board.sch]
2019-02-20 Routing WIP
    [Thermocouple-board.brd, Thermocouple-board.sch]
2019-02-21 Extended PCB length to 3.9 in
    [Thermocouple-board.brd, Thermocouple-board.sch]
2019-02-21 Updated micro USB conn to long pads
    [Thermocouple-board.brd, Thermocouple-board.sch]
2019-02-23 Mostly routed. Needs connector alignment and hold downs.
    [Thermocouple-board.brd, Thermocouple-board.sch]
2019-02-24 Added ground TPs
    [Thermocouple-board.brd, Thermocouple-board.sch]
2019-02-24 Moved LEDs to uper right corner
    [Thermocouple-board.brd]
2019-02-24 Reroute efuse
    [Thermocouple-board.brd, Thermocouple-board.sch]
2019-02-25 PCB101_A Released and ordered
    [PCBA101_A.brd]
2019-02-25 Cleanup filenames; add PDFs
    [PCB101_A.brd]
2019-02-25 Added PCB100_A
    [PCB100_A.brd]
2019-02-25 Move PCB100_A to release folder
    [PCB100_A.brd]
2019-02-25 Fix view on PCB101_A.brd
    [PCB101_A.brd]
2019-03-21 Update values on schematic
    [Thermocouple-board.brd, Thermocouple-board.sch]

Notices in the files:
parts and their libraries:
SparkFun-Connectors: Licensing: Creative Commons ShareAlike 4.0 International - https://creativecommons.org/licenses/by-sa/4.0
